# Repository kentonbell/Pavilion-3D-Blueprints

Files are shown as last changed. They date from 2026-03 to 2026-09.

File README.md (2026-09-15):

# Pavilion 3D Blueprints — From Survey to Built Structure





A complete design-to-construction record for a large outdoor pavilion: site reference, dimensional drawings, a detailed CAD assembly, Unity visualization, integrated electrical/audio planning, and photographs of the finished structure in use.

This was not only a modeling exercise. The pavilion was designed and constructed between May and July 2024, and the repository preserves the digital decisions that guided the physical build.

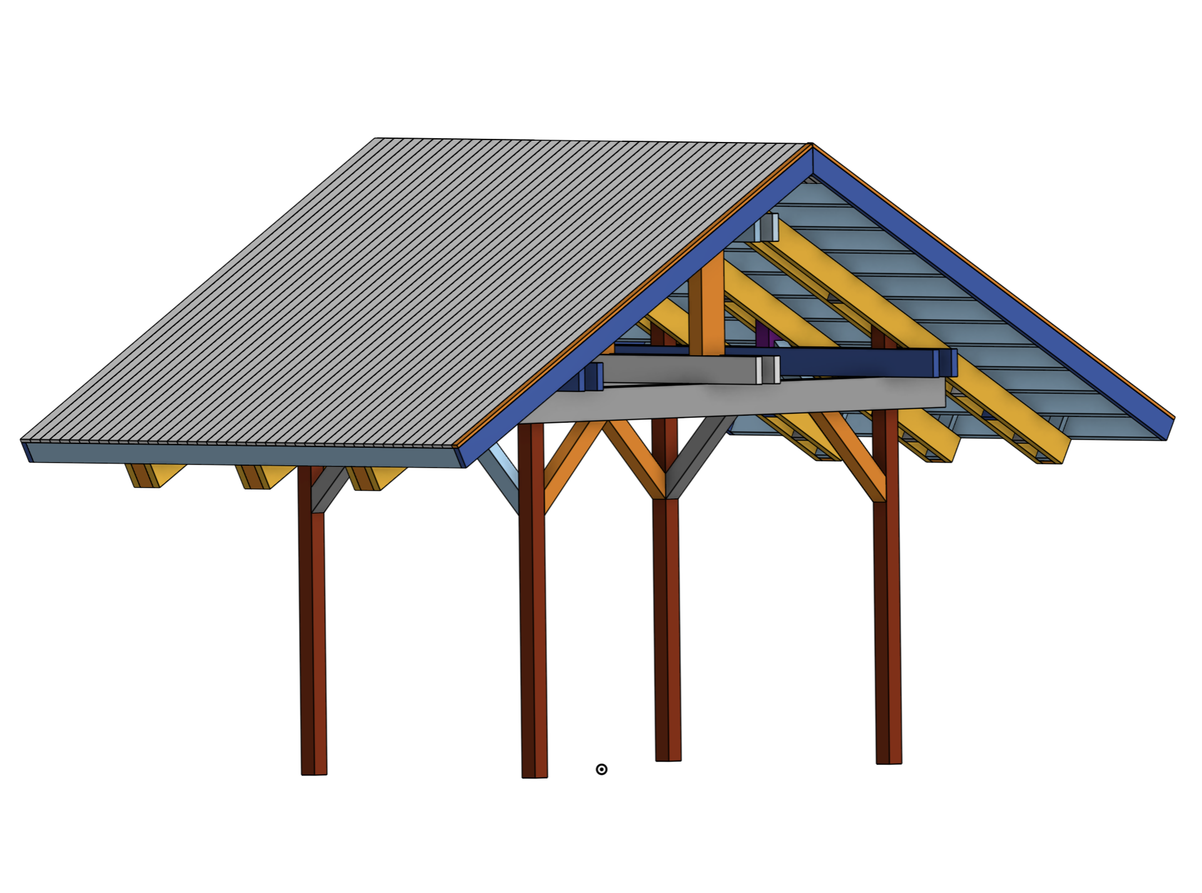
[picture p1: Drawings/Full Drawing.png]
Full color-coded pavilion model


## Project scope

The pavilion uses a four-post frame and pitched roof over an approximately 34.63-foot north–south span and 20.42-foot east–west width. The model documents the primary posts, perimeter beams, joists, rafters, purlins, spacers, trim, diagonal reinforcement, roof surfaces, floor/site relationship, and equipment placement.

The planning set also records:

- approximately 21.27 feet of total structure height
- 56-inch below-grade post embedment
- 12 main roof rafters
- approximately 24-inch purlin-support spacing
- roof and cut geometry captured in dimensioned elevations
- underground power, switched circuits, XLR audio, and Cat6-compatible conduit routes

## Design workflow

### 1. Site and footprint

The satellite view establishes the pavilion's location and relationship to the surrounding hardscape before structure and roof details are considered.

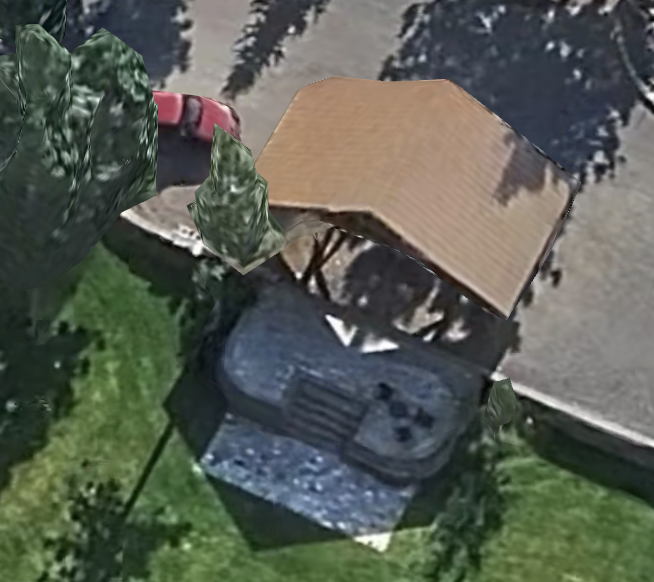
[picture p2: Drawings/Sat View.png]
Satellite view of the pavilion site


### 2. Structural assembly

The roofless model exposes the load path and makes the intersecting beam, joist, rafter, spacer, and bracing systems easier to inspect.

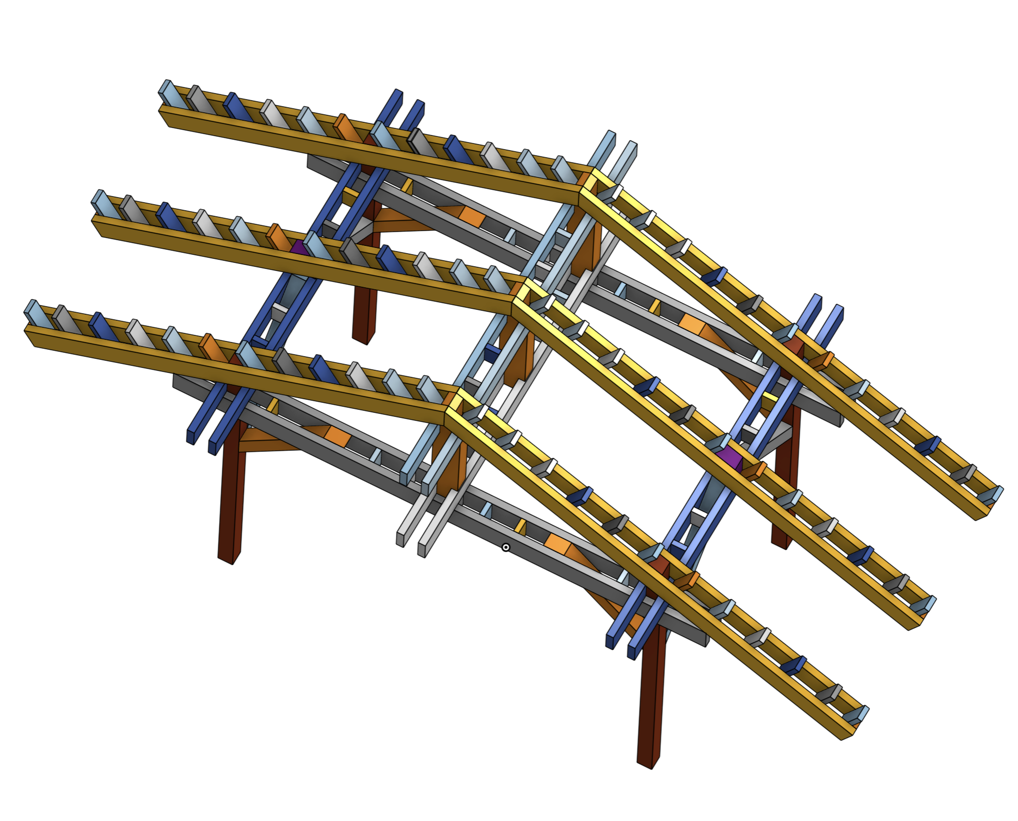
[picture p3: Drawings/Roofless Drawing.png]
Roofless structural model


### 3. Dimensioned roof planning

The roof drawing records pitch, rafter/purlin placement, overhangs, and key spacing values used to translate the 3D model into field measurements.

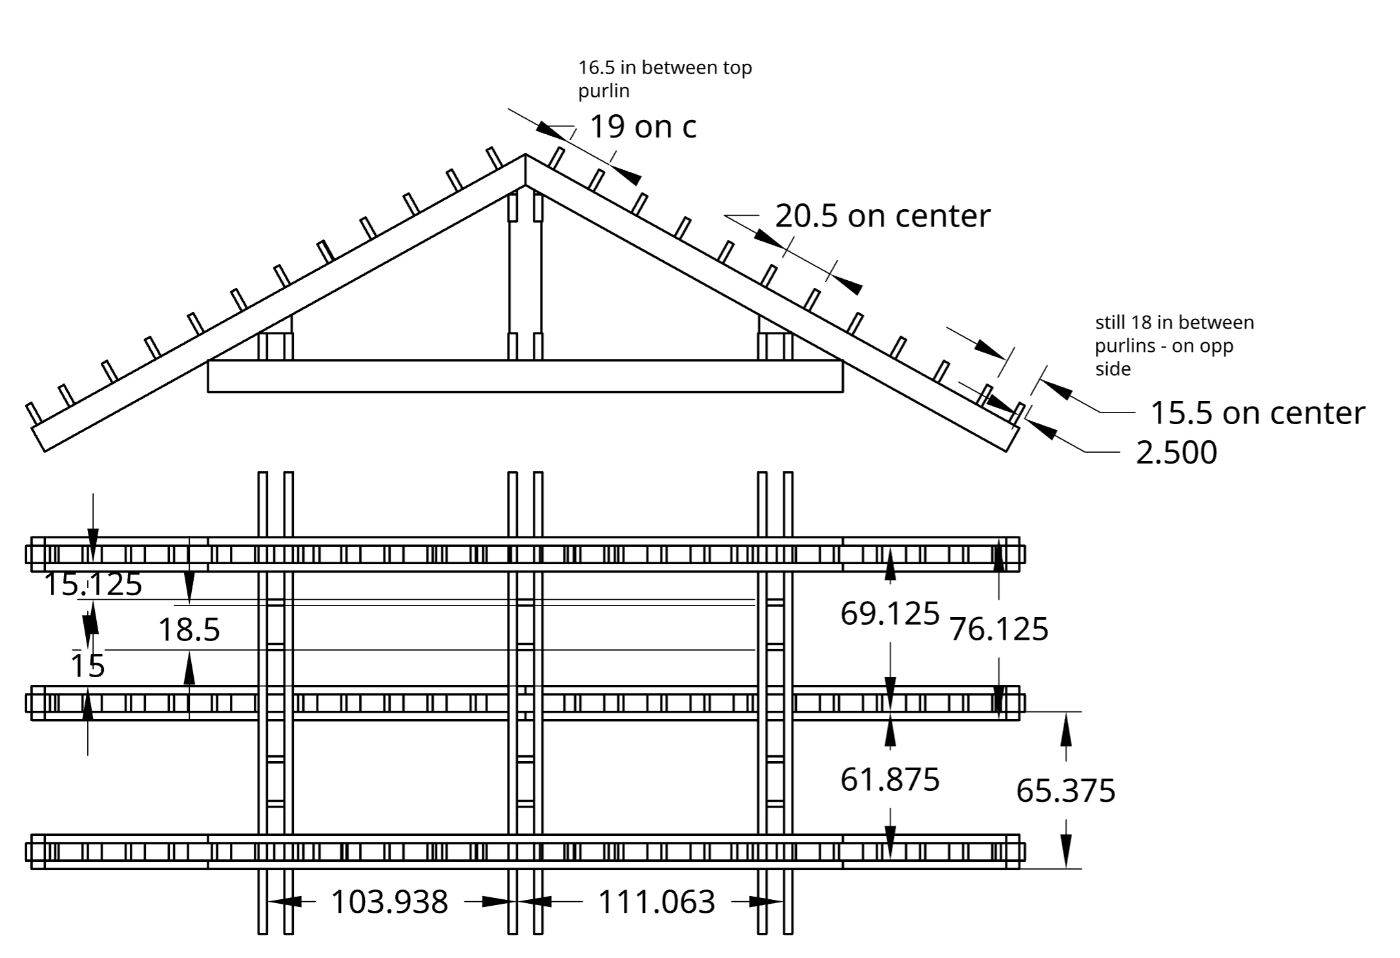
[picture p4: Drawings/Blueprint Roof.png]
Dimensioned roof blueprint


### 4. Elevation and below-grade planning

The side blueprint brings together above-grade height, post depth, roof peak, and framing relationships in one build reference.

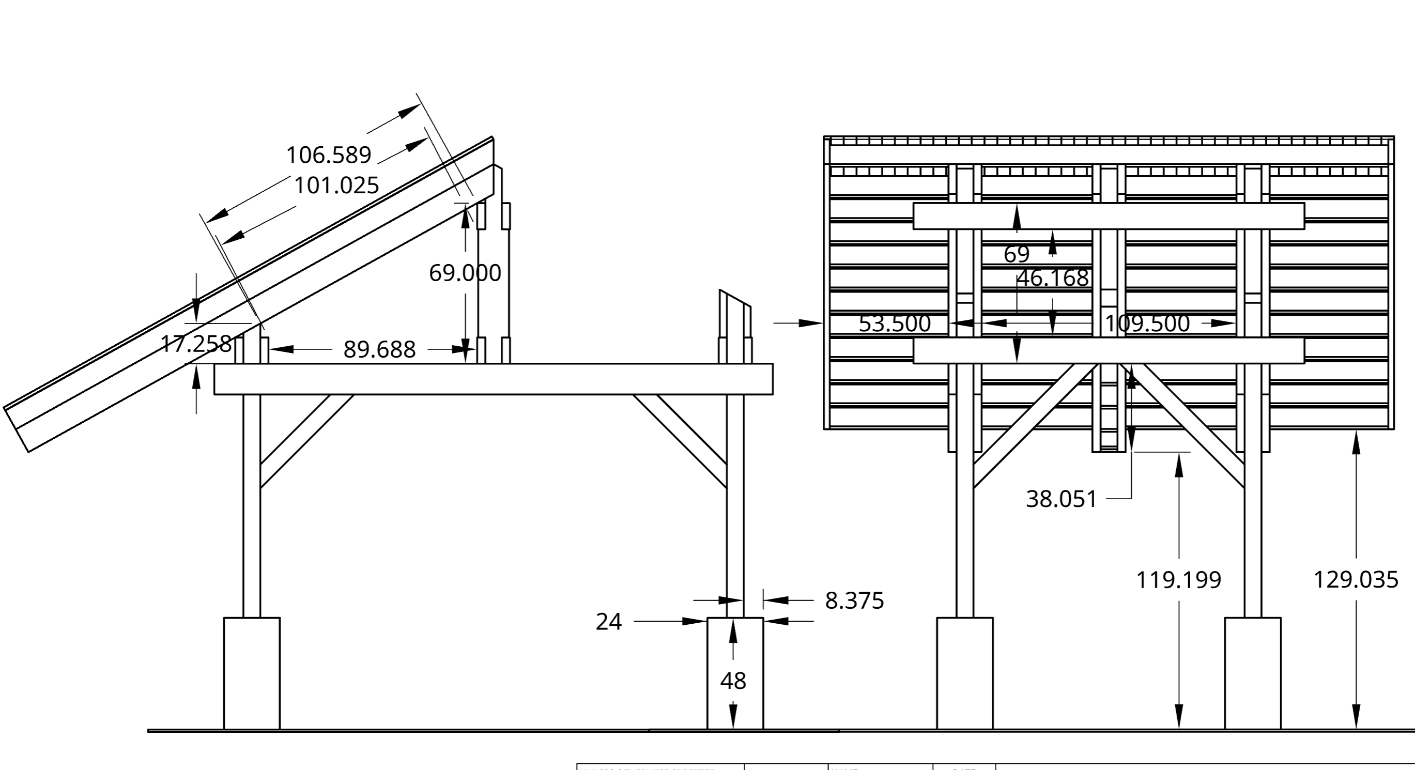
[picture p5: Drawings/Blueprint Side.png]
Dimensioned side blueprint


### 5. Visualization and systems planning

The Unity project imports the pavilion and speaker models so the structure can be reviewed spatially. Custom scripts support camera movement and object visibility, while prefabs and transparent cone materials help visualize speaker placement/coverage. The repository also includes a proposal document and hundreds of Parasolid (`.x_t`) component exports from the CAD assembly.

## Construction and finished pavilion

A gallery, moving from framing and fabrication, to the completed gathering space.

<table>
  <tr>
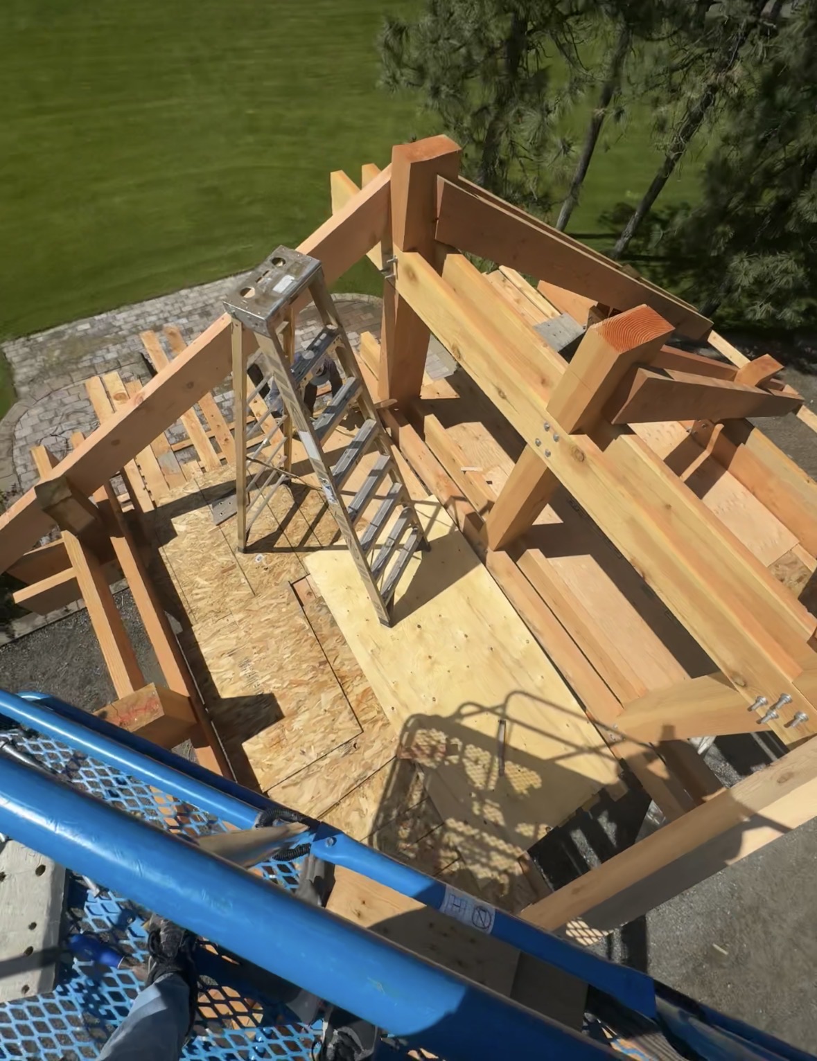
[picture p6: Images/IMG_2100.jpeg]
Pavilion framing viewed from above
    <td width="50%"><br><sub>Framing and joinery viewed from the lift.</sub></td>
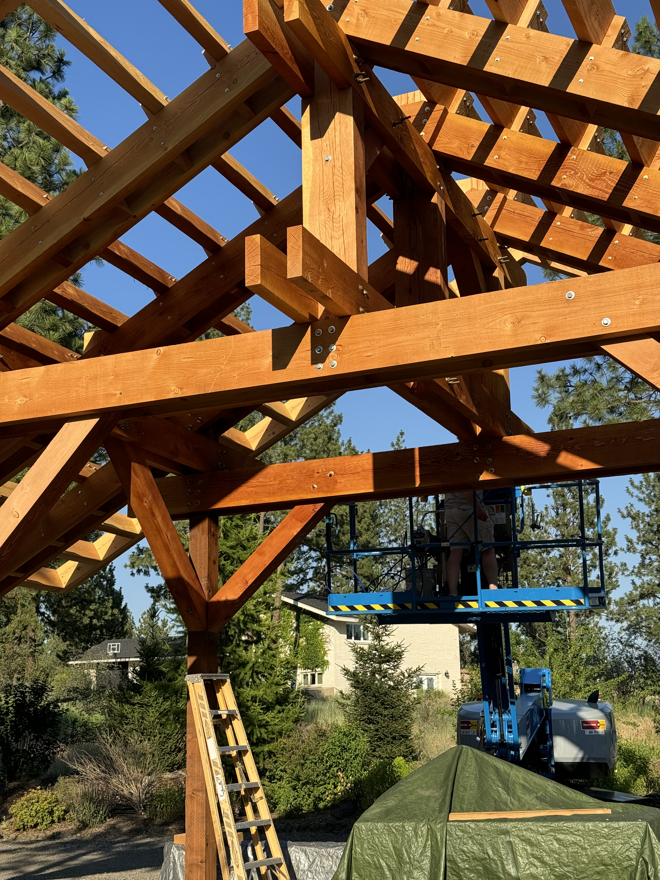
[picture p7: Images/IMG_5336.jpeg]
Rafter and bracing installation
    <td width="50%"><br><sub>Rafters, bracing, and intersecting members during construction.</sub></td>
  </tr>
  <tr>
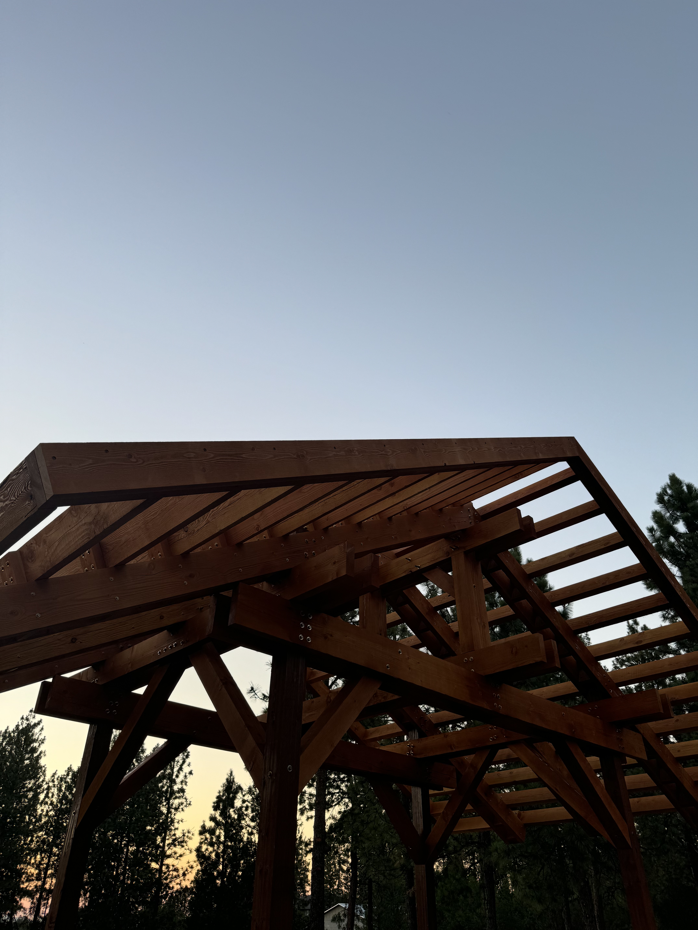
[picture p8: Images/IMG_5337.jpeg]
Roof framing silhouette
    <td><br><sub>The pitched roof geometry taking shape.</sub></td>
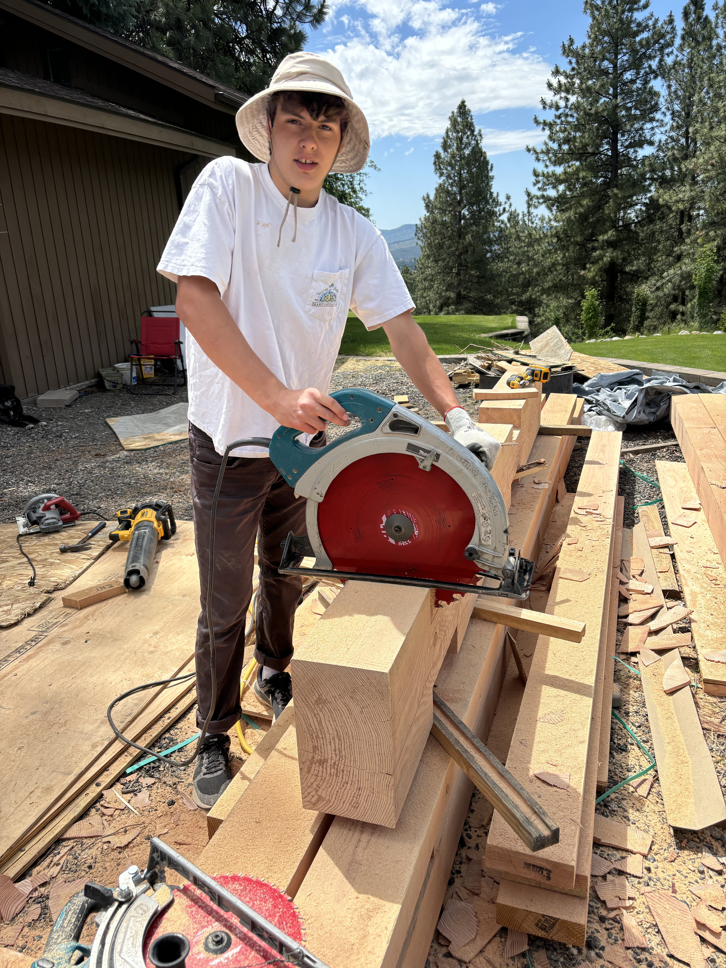
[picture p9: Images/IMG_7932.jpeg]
Cutting structural lumber
    <td><br><sub>On-site fabrication translating dimensions into parts.</sub></td>
  </tr>
  <tr>
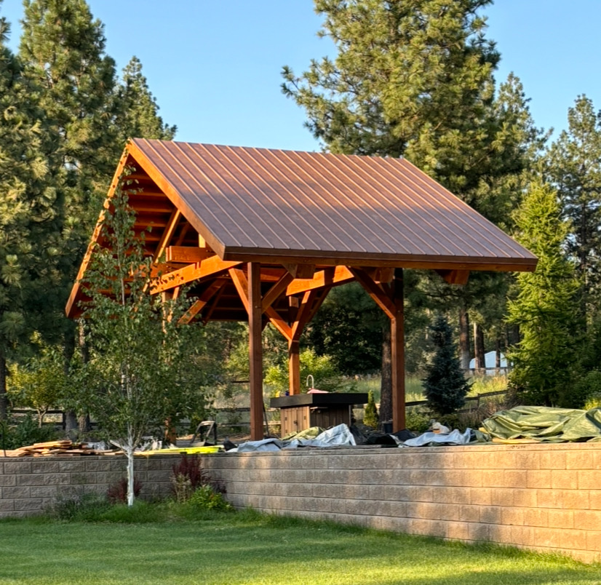
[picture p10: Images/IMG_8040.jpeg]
Pavilion with roof installed
    <td><br><sub>Roof installation and the emerging full silhouette.</sub></td>
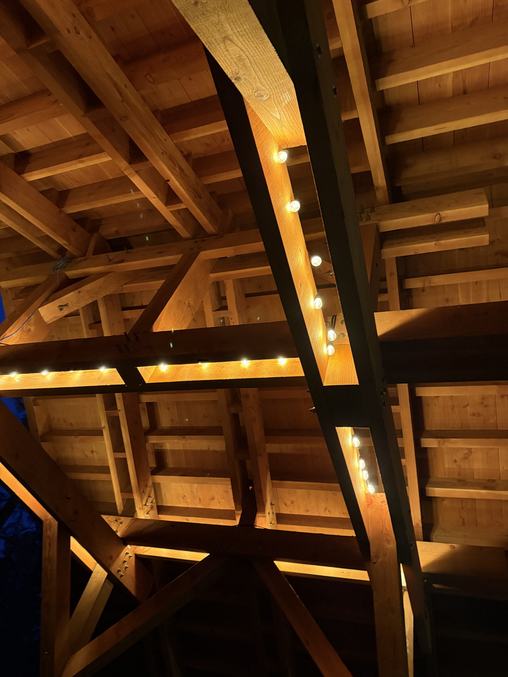
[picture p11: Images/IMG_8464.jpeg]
Integrated pavilion lighting
    <td><br><sub>Lighting integrated into the exposed timber structure.</sub></td>
  </tr>
  <tr>
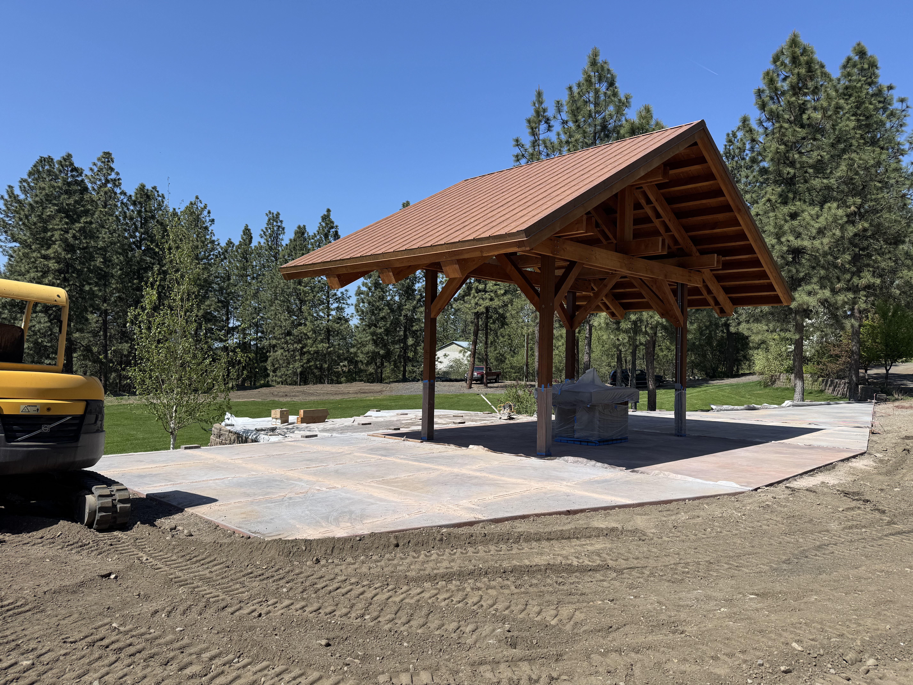
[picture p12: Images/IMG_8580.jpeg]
Completed pavilion and hardscape
    <td><br><sub>Completed shell with surrounding hardscape underway.</sub></td>
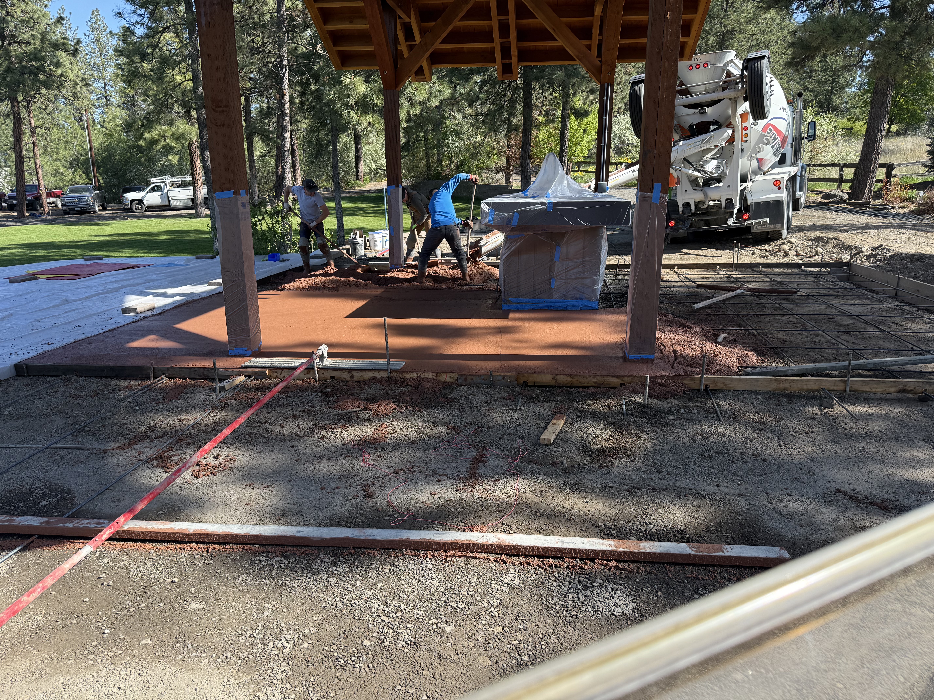
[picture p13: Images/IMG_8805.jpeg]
Outdoor kitchen installation
    <td><br><sub>Interior amenity and site work beneath the pavilion.</sub></td>
  </tr>
  <tr>
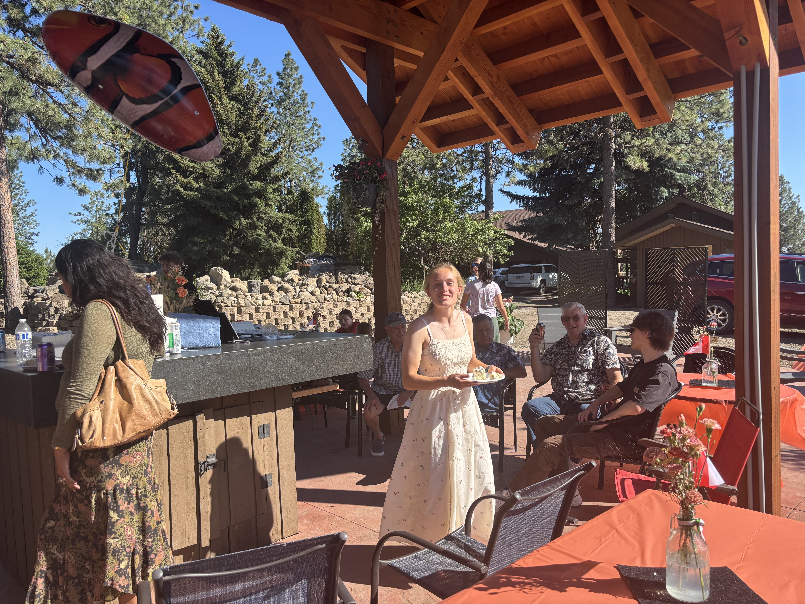
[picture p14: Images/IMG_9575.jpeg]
Gathering hosted beneath the pavilion
    <td><br><sub>The finished structure serving as a gathering space.</sub></td>
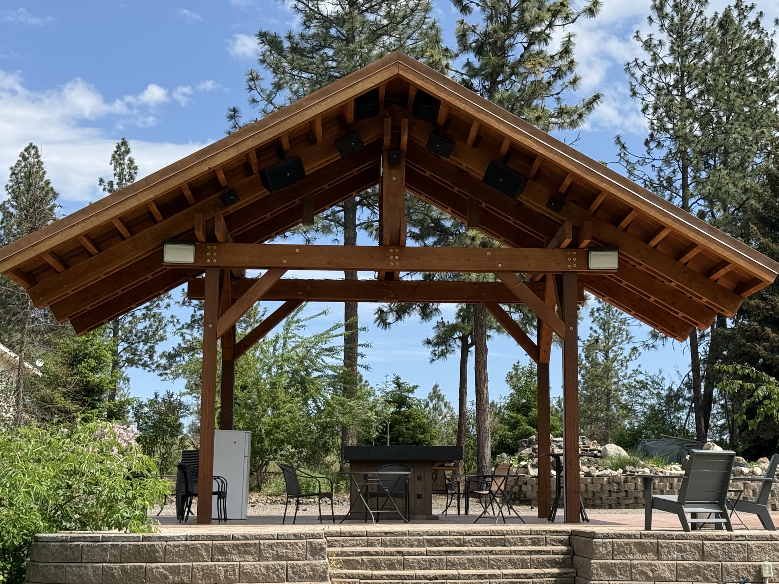
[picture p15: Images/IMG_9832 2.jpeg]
Front view of completed pavilion
    <td><br><sub>Final front elevation and exposed timber frame.</sub></td>
  </tr>
</table>

## Structural and systems thinking

The project required coordination across disciplines. Frame geometry had to be buildable; roof members had to align across a large span; equipment and conduit had to be anticipated before finishes; and the digital model had to remain understandable enough to guide work in the field.

The result demonstrates a full feedback loop:

```text
site observation → measured model → dimensioned drawings → fabrication
       ↑                                                    ↓
       └──────────── verification against the build ────────┘
```

## Explore the repository

```text
.
├── Drawings/                          # Five presentation and blueprint views
├── Images/                            # Ten construction/final photographs
├── Pavilion 12.0 CAD/                 # Parasolid component exports
├── Assets/                            # Unity models, materials, prefabs, scripts, scenes
├── Packages/                          # Unity package manifest and lockfile
├── ProjectSettings/                   # Reproducible Unity project configuration
├── Pavilion obj.dae                   # Combined pavilion model export
└── Proposal.docx                      # Project proposal
```

Open the root folder as a Unity project to explore the visualization. CAD-capable software that supports Parasolid can inspect the individual `.x_t` components.

## Skills demonstrated

CAD assembly, architectural visualization, Unity, dimensional documentation, design-for-construction, field fabrication, electrical/audio systems planning, 3D asset integration, and carrying a complex project from concept through physical completion.

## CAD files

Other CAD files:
Pavilion 12.0 CAD/Gazebo 12.0 - Part 10.x_t
Pavilion 12.0 CAD/Gazebo 12.0 - Part 100.x_t
Pavilion 12.0 CAD/Gazebo 12.0 - Part 101.x_t
Pavilion 12.0 CAD/Gazebo 12.0 - Part 102.x_t
Pavilion 12.0 CAD/Gazebo 12.0 - Part 103.x_t
Pavilion 12.0 CAD/Gazebo 12.0 - Part 104.x_t
Pavilion 12.0 CAD/Gazebo 12.0 - Part 105 2.5x9.25x205.663 angled 34.479.x_t
Pavilion 12.0 CAD/Gazebo 12.0 - Part 105.x_t
Pavilion 12.0 CAD/Gazebo 12.0 - Part 106.x_t
Pavilion 12.0 CAD/Gazebo 12.0 - Part 107.x_t
Pavilion 12.0 CAD/Gazebo 12.0 - Part 108.x_t
Pavilion 12.0 CAD/Gazebo 12.0 - Part 11 DELETE.x_t
Pavilion 12.0 CAD/Gazebo 12.0 - Part 110.x_t
Pavilion 12.0 CAD/Gazebo 12.0 - Part 111.x_t
Pavilion 12.0 CAD/Gazebo 12.0 - Part 112.x_t
Pavilion 12.0 CAD/Gazebo 12.0 - Part 113.x_t
Pavilion 12.0 CAD/Gazebo 12.0 - Part 114.x_t
Pavilion 12.0 CAD/Gazebo 12.0 - Part 115.x_t
Pavilion 12.0 CAD/Gazebo 12.0 - Part 116.x_t
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
